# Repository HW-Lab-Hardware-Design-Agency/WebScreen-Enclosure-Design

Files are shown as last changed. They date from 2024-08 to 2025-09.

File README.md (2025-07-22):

   
# WebScreen-Enclosure-Design
## Description

This repository contains design files and technical documentation for the webscreen enclosure. The enclosure has been designed to provide a robust and functional solution, optimizing hardware integration with an improved fastening system using insertion and friction instead of adhesives.



## Main Features

+ Optimized Design: Fastening via insertion and friction for greater stability and easy assembly.

+ Compatibility: Specifically designed for the webscreen with a custom support base.

+ Recommended Materials: `PLA`, `ABS`, depending on mechanical and thermal resistance requirements.

+ Source Files: Models in [Freecad](https://www.freecad.org/) format.

## Project structure
  • `/Documentation` - Contains the technical manual with specifications and assembly guides..

  • `/STL_Files` - contains design files in .STL formats for 3D printing.

  • `/Editable_files_in_Freecad` - contains design files in .FCStd formats for 3D edition in [Freecad](https://www.freecad.org/).

## Assembly Instructions
  • Watch the [assembly instructions video](https://www.youtube.com/watch?v=CHH5L84EN5o&t=1s).

  • You can also find a detailed [guide to fix the webscreen](https://es.ifixit.com/Desmontaje/WebScreen+Teardown/181334).

## 3D Printing Specifications for WebScreen
To ensure optimal quality and functionality, please follow these printing settings:

  • Layer height: 0.2 mm
  
  • Infill density: 20%
  
  • Infill pattern: Gyroid or Grid (for strength and flexibility)
  
  • Wall thickness: 1.2 mm (at least 3 perimeters)
  
  • Top/bottom layers: 4
  
  • Printing material: PLA, PETG, or ABS (PETG recommended for better durability)
  
  • Nozzle diameter: 0.4 mm
  
  • Print speed: 50-60 mm/s
  
  • Supports: Only if necessary (use tree supports for easy removal)
  
  • Bed adhesion: Brim or Raft if necessary (for better grip)
  
  • Cooling fan: 100% (except for the first few layers)
  
  • Temperature Nozzle: 200-220°C (depending on material)
  
  • Temperature Bed: 60°C for PLA, 80°C for PETG, 100°C for ABS

Make sure your print bed is well-leveled, and the first layer adheres properly to avoid warping. If using ABS, print in an enclosed chamber to prevent warping and cracking.
For best results, post-processing such as light sanding or acetone smoothing (for ABS) can be applied.

## License
This project is open source. See the [LICENSE](https://github.com/HW-Lab-Hardware-Design-Agency/WebScreen-Enclosure-Design/blob/main/LICENSE) file for details.

## Contact

For inquiries or contributions, please contact the development team through the repository issues or via email.



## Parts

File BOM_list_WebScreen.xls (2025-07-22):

Pos | Part | Qty
1 | Pcb | 1
2 | Bottom Enclosure | 1
3 | On/Off Button | 1
6 | Mount Adjustment Hook | 2
7 | Pivot support | 1
8 | Screw M3*10 | 2
9 | Screw M1.4*0.3*3mm | 2
12 | Main body Enclosure | 1
13 | Display DO0200FS01 | 1
14 | Top Enclosure | 1
15 | Cap | 1

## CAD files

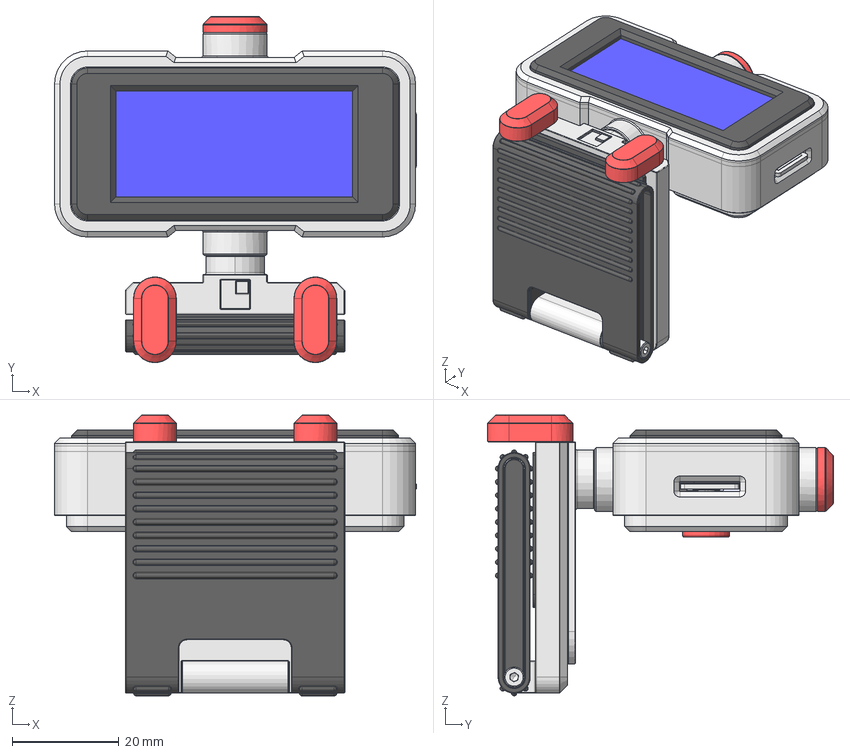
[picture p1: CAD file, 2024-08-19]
Small Version/main_body.FCStd
67.7 x 64.7 x 52.5 mm
SS_Mount Body Upper V1.0
SS_Mount Lower Outer Rubber V1.0
SS_Mount Lower Inner V1.0
socket head cap screw_am_B18.3.1M - 2 x 0.4 x 3 Hex SHCS -- 3NHX003
socket head cap screw_am_B18.3.1M - 2 x 0.4 x 3 Hex SHCS -- 3NHX004
SS_Mount Upper Rubber Protector V1.0
female thread002
SS_Mount Adjustment Hook V1.002
SS_Mount Adjustment Hook V1.003
L_0402_1005Metric
C_0402_1005Metric
r_0402_h040
PRO-OB-440
C_0402_1005Metric002
ASSEMBLY
C_0603_1608Metric
r_0402_h042
C_0603_1608Metric002
L_0402_1005Metric002
C_0402_1005Metric004
LED_0603_1608Metric
BRFL2518T1R5M
BRFL2518T1R5M001
BRFL2518T1R5M002
ASSEMBLY001
ASSEMBLY002
R_0402_1005Metric
r_0402_h044
r_0402_h046
C_0402_1005Metric006
C_0402_1005Metric008
MicroSD_Socket
MicroSD_Socket001
MicroSD_Socket002
MicroSD_Socket003
MicroSD_Socket004
MicroSD_Socket005
MicroSD_Socket006
MicroSD_Socket007
MicroSD_Socket008
MicroSD_Socket009
MicroSD_Socket010
MicroSD_Socket011
MicroSD_Socket012
MicroSD_Socket013
MicroSD_Socket014
MicroSD_Socket015
MicroSD_Socket016
MicroSD_Socket017
MicroSD_Socket018
MicroSD_Socket019
MicroSD_Socket020
MicroSD_Socket021
MicroSD_Socket022
LQM2HPN1R0MJ0L
LQM2HPN1R0MJ0L001
LQM2HPN1R0MJ0L002
Crystal_SMD_3225-4Pin_3.2x2.5mm
ASSEMBLY003
ASSEMBLY004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

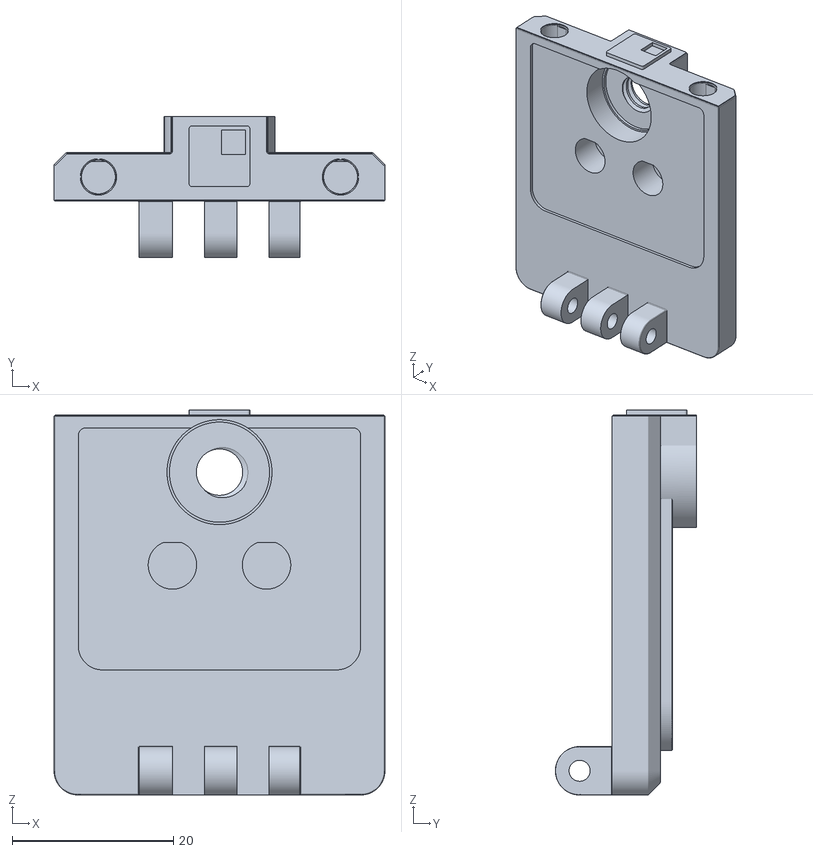
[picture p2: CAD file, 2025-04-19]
STL_Files/Main_body(White).stl
41.0 x 17.5 x 47.7

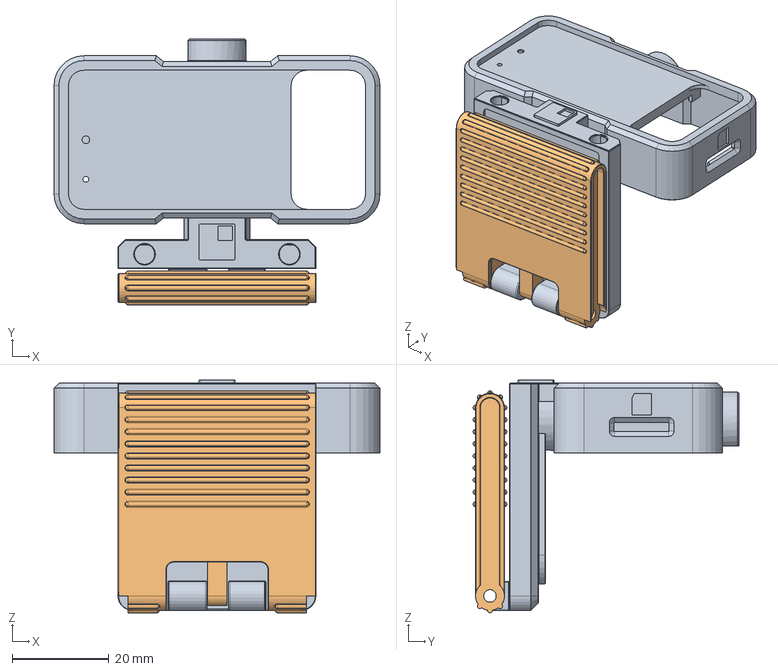
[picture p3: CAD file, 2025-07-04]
Editable_files_in_Freecad/Assembly_v2.FCStd
67.5 x 55.1 x 48.2 mm
Main_body_001
pivot_support_001

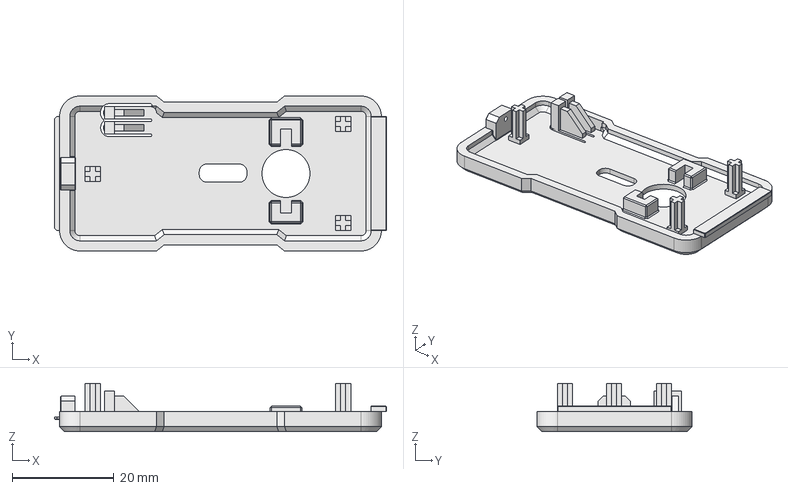
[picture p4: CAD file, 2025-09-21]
Editable_files_in_Freecad/Bottom_Enclosure.FCStd
65.1 x 30.4 x 9.50 mm

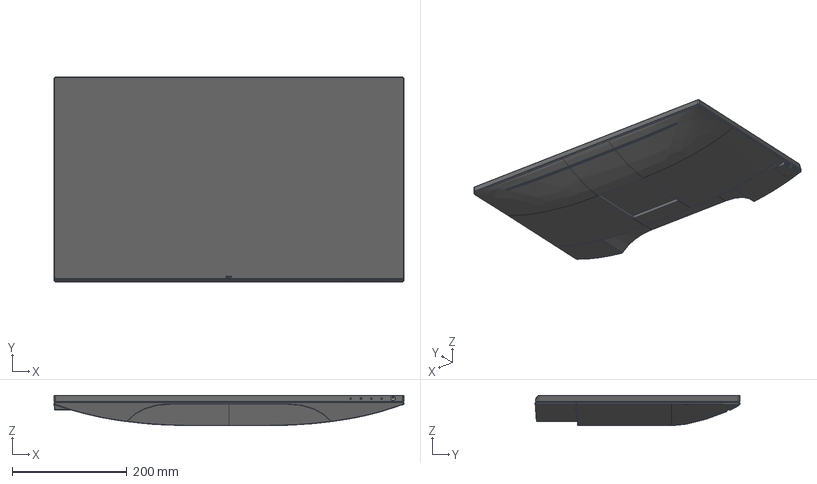
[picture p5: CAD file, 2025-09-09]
Editable_files_in_Freecad/Monitor.FCStd
610.0 x 357.0 x 53.1 mm
Dell 27 monitor
Dell 27 monitor001
Dell 27 monitor002
Dell 27 monitor003
Dell 27 monitor004
Dell 27 monitor005
Dell 27 monitor006
Dell 27 monitor007
Dell 27 monitor008
Dell 27 monitor009
Dell 27 monitor010
Dell 27 monitor011
Dell 27 monitor012
Dell 27 monitor013
Dell 27 monitor014
Dell 27 monitor015
Dell 27 monitor016
Dell 27 monitor017
Dell 27 monitor018
Dell 27 monitor019
Dell 27 monitor020
Dell 27 monitor021
Dell 27 monitor022

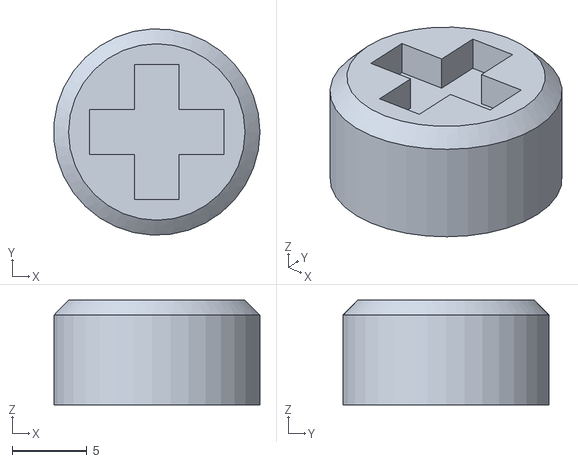
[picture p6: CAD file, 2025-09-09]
STL_Files/Cap(red).stl
13.8 x 13.8 x 7.00

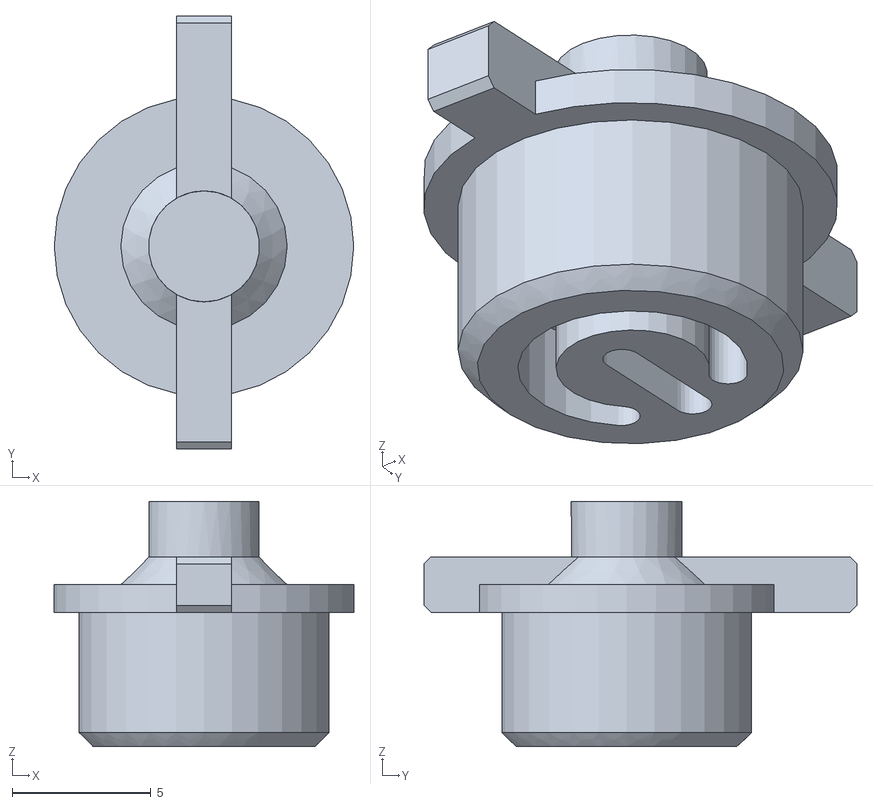
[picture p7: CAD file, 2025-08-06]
STL_Files/Red_buttom(red).stl
10.8 x 15.6 x 8.84

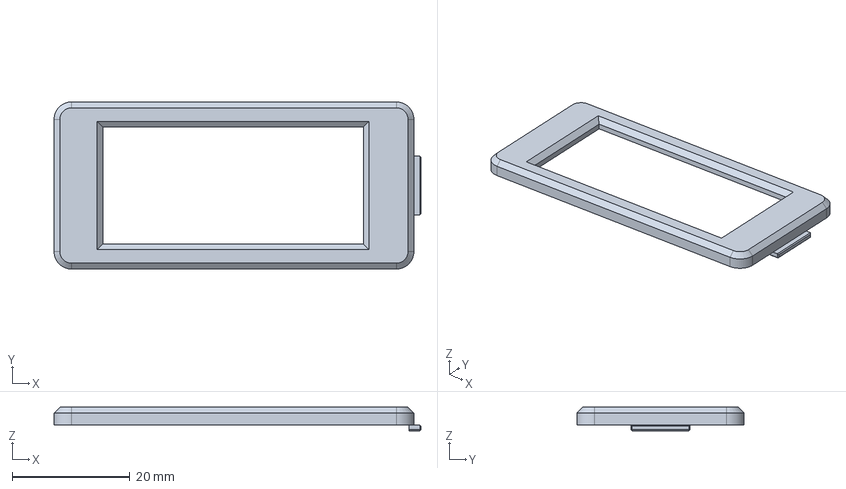
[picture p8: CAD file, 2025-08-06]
Editable_files_in_Freecad/Top_Enclosure.FCStd
62.3 x 28.4 x 4.00 mm

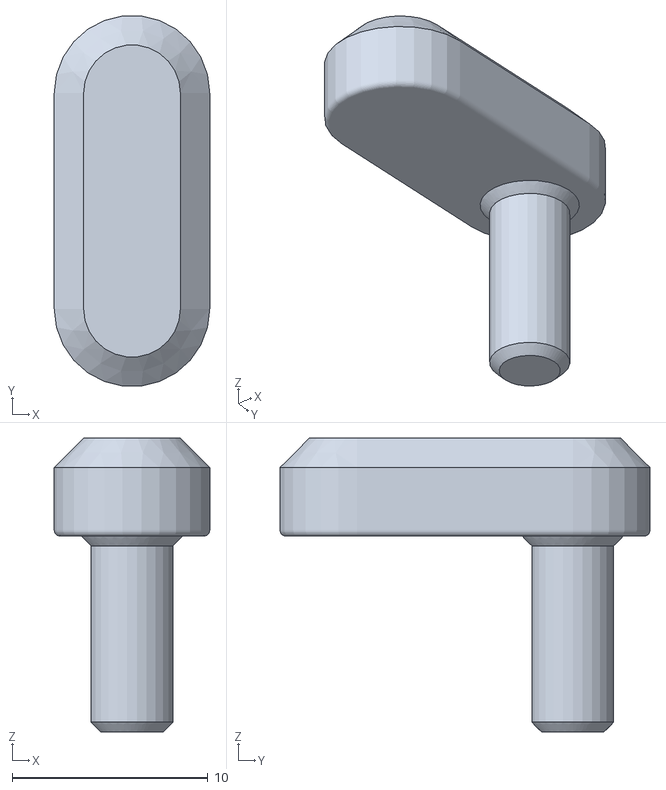
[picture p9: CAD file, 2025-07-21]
STL_Files/Mount_Adjustment_hook(Red).stl
7.94 x 18.9 x 15.0

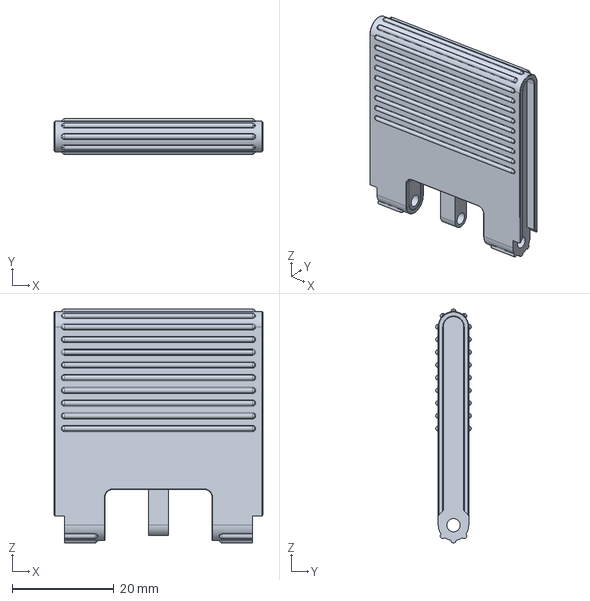
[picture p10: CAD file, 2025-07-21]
Editable_files_in_Freecad/pivot_support.FCStd
41.0 x 7.00 x 46.0 mm

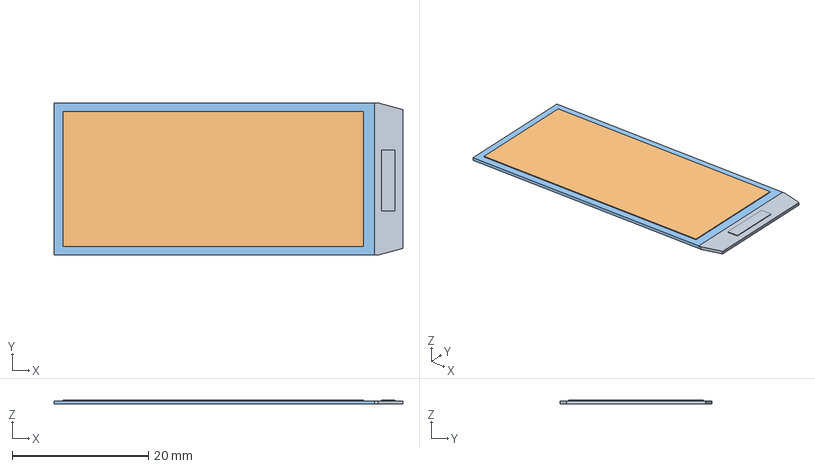
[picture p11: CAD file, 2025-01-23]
Editable_files_in_Freecad/Display_DO0200FS01.FCStd
51.3 x 22.4 x 0.64 mm

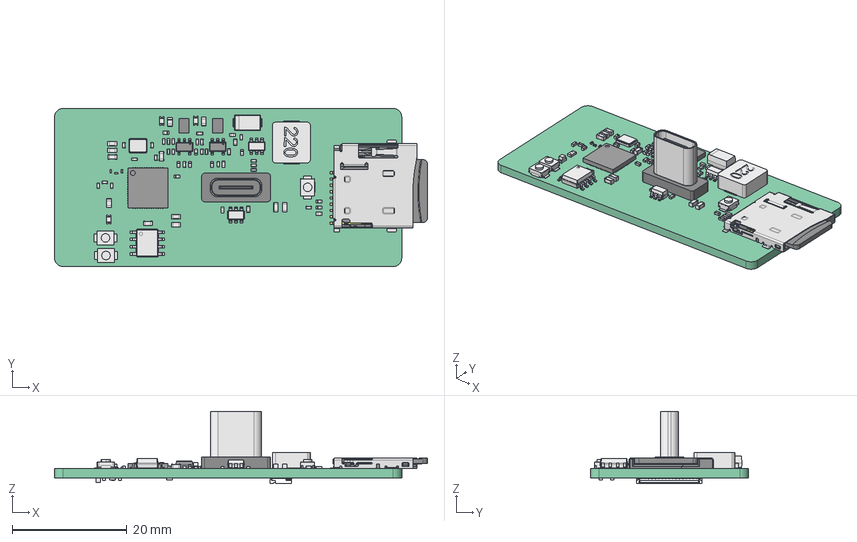
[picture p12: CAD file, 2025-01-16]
Editable_files_in_Freecad/Display_pcb.FCStd
65.1 x 27.6 x 12.6 mm
Pcb_686b
R21_r_0402_h040_d01af9244106 x 20
C17_C_0201_0603Metric_b89ab5aa9964 x 2
C4_C_0402_1005Metric_ad35c1dd326c x 24
B3U_1000P x 3
C15_C_0603_1608Metric_17e78e0e3195 x 7
L2_L_0402_1005Metric_cf0443b79bf7 x 2
DS2_LED_0603_1608Metric_Castellated_210b8ad15fde x 3
BRFL2518T1R5M x 2
BRFL2518T1R5M001 x 2
BRFL2518T1R5M002 x 2
c_0603_h078 x 3
U3_SOT_23_6_41fc66089ef8 x 2
Case^MicroSD_Socket
Insert^MicroSD_Socket
Brace^MicroSD_Socket
Spring^MicroSD_Socket
Lid^MicroSD_Socket
Pin_Middle^MicroSD_Socket
Pin_Middle^MicroSD_Socket001
Pin_Middle^MicroSD_Socket002
Pin_Middle^MicroSD_Socket003
Pin_Middle^MicroSD_Socket004
Pin_Short^MicroSD_Socket
Pin_Long^MicroSD_Socket
Pin_Long^MicroSD_Socket001
MicroSD_Card^MicroSD_Socket
MicroSD_Card^MicroSD_Socket001
MicroSD_Card^MicroSD_Socket002
MicroSD_Card^MicroSD_Socket003
MicroSD_Card^MicroSD_Socket004
MicroSD_Card^MicroSD_Socket005
MicroSD_Card^MicroSD_Socket006
MicroSD_Card^MicroSD_Socket007
MicroSD_Card^MicroSD_Socket008
Pin_CardIn^MicroSD_Socket
Y1_Crystal_SMD_3225-4Pin_3.2x2.5mm_d5f2c4821880
PinsArrayL x 2
PinsArrayL001 x 2
PinsArrayL002 x 2
PinsArrayR x 2
PinsArrayR001 x 2
D1_D_SMA_0f2286977986
Cuerpo
L3_L_0201_0603Metric_520d9d73161f
soic_8_39x49_p127
ThermalPin
PinsArrayLR
PinsArrayLR001
PinsArrayLR002
PinsArrayLR003
PinsArrayLR004
PinsArrayLR005
PinsArrayLR006
PinsArrayLR007
PinsArrayLR008
PinsArrayLR009
PinsArrayLR010
PinsArrayLR011
PinsArrayLR012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

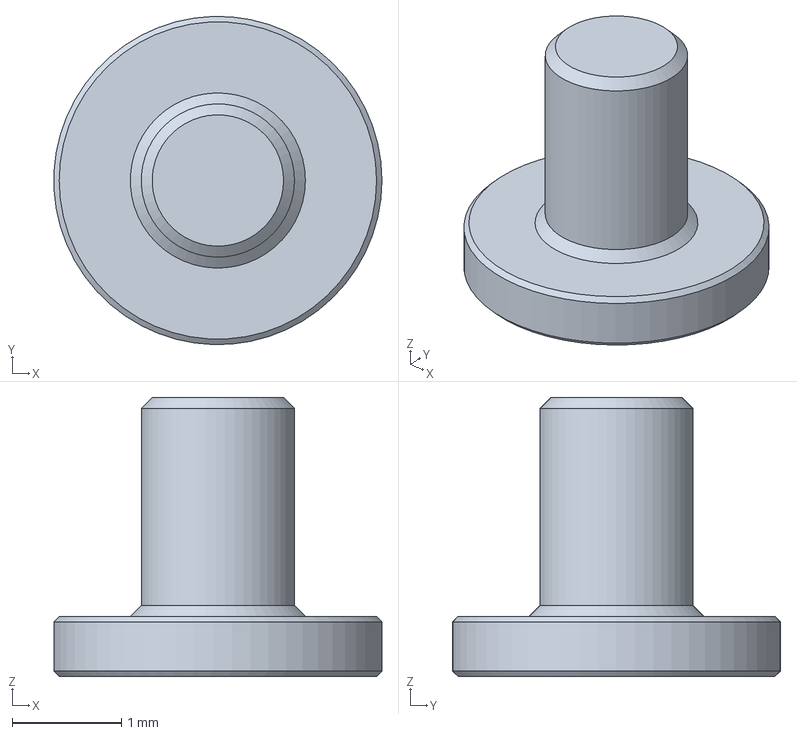
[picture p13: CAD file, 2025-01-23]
Editable_files_in_Freecad/M1.4_0.3_3mm_Screw.FCStd
3.00 x 3.00 x 2.55 mm

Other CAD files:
STL_Files/Bottom_enclosure(white).stl
Editable_files_in_Freecad/Cap.FCStd
STL_Files/Top_Enclosure(Black).stl
Editable_files_in_Freecad/Red_Buttom.FCStd
Editable_files_in_Freecad/Mount_adjustment_hook.FCStd
Editable_files_in_Freecad/M3x10 Philips Screw.FCStd

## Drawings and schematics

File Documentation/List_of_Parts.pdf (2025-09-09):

## List of P arts

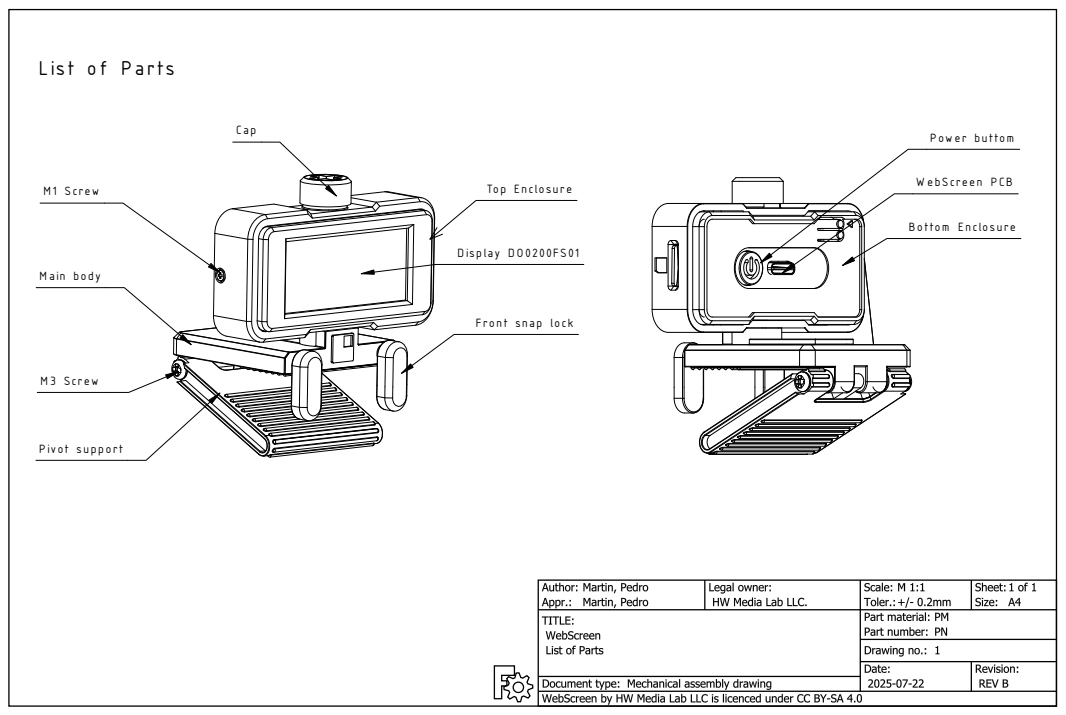
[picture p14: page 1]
Cap; Top Enclosure; M ain body; P ivot support; M 3 S cre w; M 1 S cre w; D isplay D O 0200F S 01; P o w er buttom; B ottom Enclosure; W eb S creen P C B

Front snap lock

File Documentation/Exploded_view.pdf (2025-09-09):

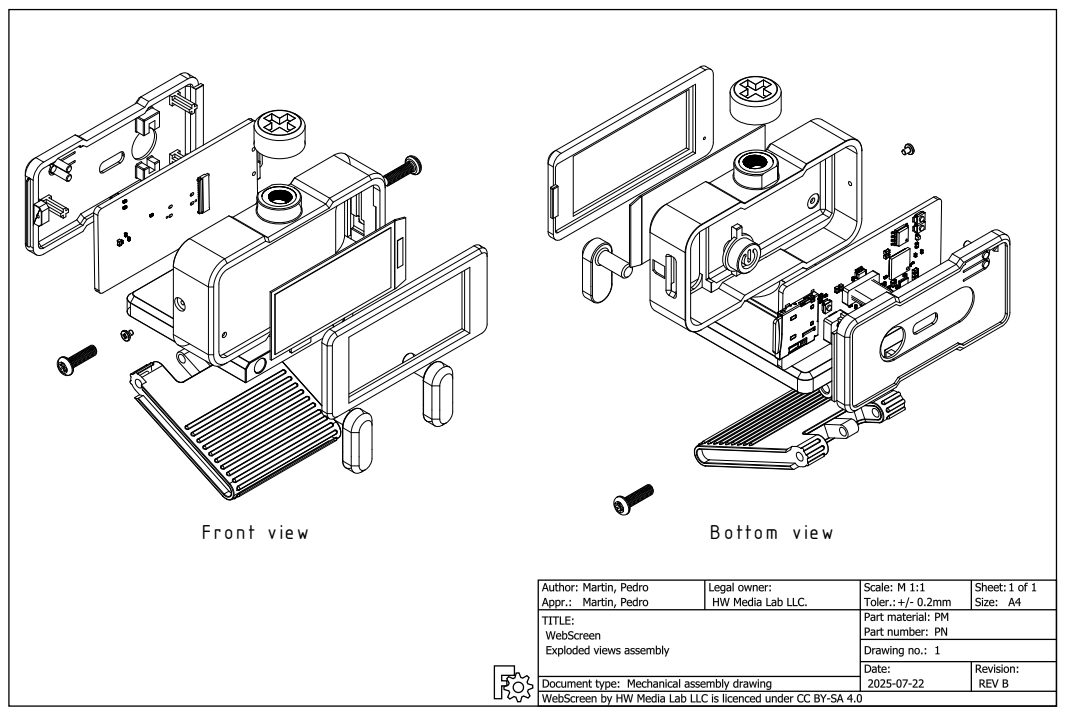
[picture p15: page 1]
Front vie w; B ottom vie w

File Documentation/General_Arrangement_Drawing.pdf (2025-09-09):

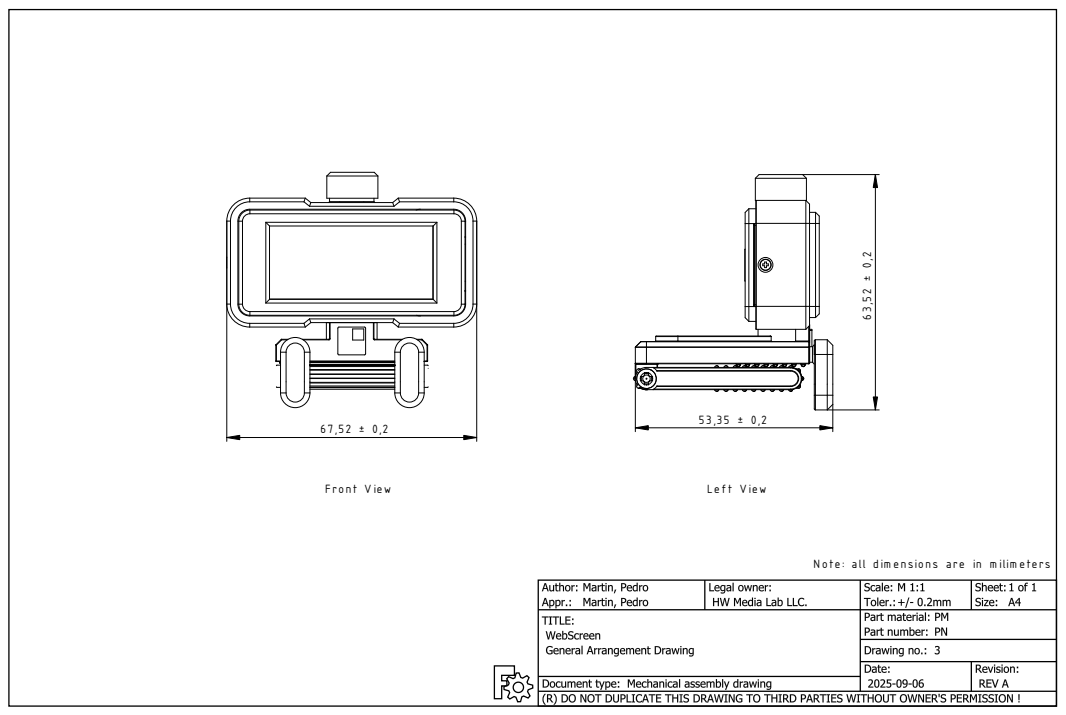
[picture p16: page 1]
Front V ie w; Left V ie w

N ote: all dim ensions are in m ilim eters

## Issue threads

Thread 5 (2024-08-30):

Multiple issues: Top cap, screw sizes, bottom clamps, etc

eleonel, 2024-08-30:
- Top cap: Increase height a tiny bit (what do you think?)
- Small gap: I’m afraid of this gap, maybe it is because of my printer but we should check we have no visible gaps.
- Bottom screw: It doesn’t adjust very well, compared with the top one. The top one adjusts quite tight.
- Clamps: For some reason the left clamp is not as tight as the right one, maybe it is my printer? I printed the files from the folder, so maybe one of them is smaller in diameter than the other?

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

**Printing settings (Bambu Lab P1P)**

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

eleonel, 2025-04-14:
All issues are resolved now with the latest commit.

Closed 2025-04-14.

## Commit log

2024-07-08 Create Bottom Enclosure
    [Bottom_Enclosure.FCStd]
2024-07-11 First iteration of the large version
    [Assembly.FCStd, Bottom_Enclosure.FCStd, Bottom_Enclosure.stl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]
2024-07-15 Add small version enclosure
    [Top_Enclosure.FCStd, Top_Enclosure.stl, Top_Enclosure_Black.FCStd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]
2024-07-18 Width of 2mm for front enclosure (Small Version)
    [Top_Enclosure.FCStd, Top_Enclosure.stl]
2024-07-19 Add support for enclosure and support for videocam
    [Top_Enclosure.FCStd, Top_Enclosure.stl]
2024-07-24 Small version Enclosure. Design with one screw. First functional iteration
    [Bottom_Enclosure.stl, Top_Enclosure.FCStd, Top_Enclosure.step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]
2024-07-29 Exploded view Diagram
    [Bottom_Enclosure.stl, Top_Enclosure.FCStd, Top_Enclosure.step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]
2024-08-05 Add 3d model of PCB v2
    [main_body.FCStd]
2024-08-07 Add slot for TF card memory
    [main_body.FCStd]
2024-08-12 New screw for bottom enclosure (Use M1 screws)
    [Bottom_Enclosure.stl, Top_Enclosure.stl, Top_Enclosure_Black.stl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]
2024-08-17 Add SS_Mount_Adjustment_Hook large version
    [Mount_Lower_Rubber_Inner.stl, Mount_Upper_Rubber_Protector.stl, SS_Mount_Adjustment_Hook_large_version.FCStd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]
2024-08-17 Add STL File SS_Mount_Adjustment_Hook_large_version
    [SS_Mount Adjustment Hook V1.0.stl]
2024-08-19 Fix Mount Adjustment Hook large version
    [SS_Mount_Adjustment_Hook_large_version.FCStd, SS_Mount_Adjustment_Hook_large_version.stl, Thread_Cap.stl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]
2024-08-29 Version with nut and screw incorporated in the top enclosure part
    [Bottom_Enclosure.stl, Display_pcb.stl, Thread_Cap_v2.stl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]
2024-12-09 Init enclosure production 3d printing
    [Bottom_Enclosure.stl, Display_pcb.stl, Locking_hinge_part1(black).stl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]
2024-12-09 Init files for production 3d printing
2024-12-11 Add STEP Files
    [Bottom_enclosure(white).step, Enclosure_display(black).step, Mount_adjustment_hook_1(red).step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]
2024-12-17 Add reset and boot buttons to WebScreen enclosure
    [Bottom_Enclosure.FCStd, Bottom_enclosure(white).step, Bottom_enclosure(white).stl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]
2024-12-17 Fix STL File Bottom Enclosure
    [Bottom_enclosure(white).stl]
2024-12-20 Marked reset button for identification
    [Bottom_Enclosure.FCStd, Bottom_enclosure(white).step, Bottom_enclosure(white).stl]
2025-01-07 Add memory card symbol to top enclosure
    [Top_enclosure(white).stl]
2025-01-16 Updated enclosure bottom with unique guide for on/off button positioning; modified on/off button design
    [Bottom_Enclosure.FCStd, Bottom_enclosure(white).step, Bottom_enclosure(white).stl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]
2025-01-23 Red Cap Change, Exploded Assembly Drawing for documentation, and .glb File Generation for Web Viewer
    [14_12_Round_head_screw.FCStd, BOM_list_WebScreen.xlsx, Bottom_Enclosure.FCStd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]
2025-02-10 DREIS Front Customization Base and Insertion-Based Pad Mounting
    [Main_body(White).stl, Mounting_pad(black).stl, Pad.FCStd]
2025-02-14 Enclosure polished design
    [Bottom_enclosure(white).step, Bottom_enclosure(white).stl, Cap(red).step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]
2025-03-09 Fix errors in .STL Files
    [RedButtom(red).stl, Top_enclosure(black).stl]
2025-04-13 Update FreeCAD source files and exported STL models
    [Cap(red).stl, Cap.FCStd, Enclosure_display(black).stl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]
2025-04-15 Fix corrupted File Enclosure display´
    [Enclosure_display(black).stl, Top_Enclosure.FCStd]
2025-04-19 Added wall thickness for proper 45 degrees printing
2025-04-19 Added stl File Main body
    [Main_body(White).stl]
2025-04-19 Init commit base integration
    [Main_body(White).stl, Main_enclosure(white).stl, Red_Buttom.FCStd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]
2025-04-19 Change on red_buttom stl file
    [Red_Buttom.FCStd, Red_buttom(red).stl]
2025-04-22 Change pivot support to production
    [Locking_hinge_part1(black).stl, pivot_support.FCStd, pivot_support_1.FCStd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]
2025-05-30 Change in mechanical fastening: Snap fit in Top Enclosure
    [Bottom_enclosure(white).stl, Enclosure_display(black).stl, Main_body(White).stl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]
2025-05-30 Fix .STL File Top Enclosure
    [Top_Enclosure(Black).stl]
2025-06-03 Reverted snap-fit, returned to mechanical fastening on Top Enclosure
    [14_12_Round_head_screw.FCStd, Top_Enclosure(Black).stl, Top_Enclosure.FCStd]
2025-06-28 changed pivot support base
    [Assembly_v2.FCStd, pivot_support.FCStd]
2025-07-04 New pivot support with 3 mm diameter
2025-07-09 Refined M3 mounting - Hole resize & Pad removal
    [Pad.FCStd, pivot_support.FCStd]
2025-07-12 Refined M3 head recess on pivot support + resized front hook diameter for interference fit (to be validated)
    [Mount_Adjustment_hook(Red).stl, Mount_adjustment_hook.FCStd, pivot_support.FCStd]
2025-07-14 Add mounting hole in top enclosure & refine hook diameter support
    [Mount_Adjustment_hook(Red).stl, Mount_adjustment_hook.FCStd, Top_Enclosure(Black).stl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]
2025-07-21 Multiple improvements around mounting, pad and hooks.
    * New pivot support with 3 mm diameter
    * Refined M3 mounting - Hole resize & Pad removal
    * Refined M3 head recess on pivot support + resized front hook diameter for interference fit (to be validated)
    * Add mounting hole in top enclosure & refine hook diameter support
    ---------
    [Mount_Adjustment_hook(Red).stl, Mount_adjustment_hook.FCStd, Pad.FCStd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]
2025-07-22 Enlarged hole in the main body to improve screwing of the top enclosure
    [BOM_list_WebScreen.xls, BOM_list_WebScreen.xlsx, Bottom_Enclosure.FCStd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]
2025-07-22 Change Main Body .STL File
2025-08-04 Change the hole to an M1 threaded hole
    [Top_Enclosure(Black).stl, Top_Enclosure.FCStd]
2025-08-06 Adjust screw hole diameter in top enclosure and add 1mm to bottom on-off
    [Red_Buttom.FCStd, Red_buttom(red).stl]
2025-09-09 Reinforced standoffs in bottom enclosure for RESET/BOOT switch support
    [Bottom_Enclosure.FCStd, Bottom_enclosure(white).stl, Cap(red).stl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]
2025-09-21 Increase bottom enclosure wall thickness from 0.75mm to 1mm for printability
    [Bottom_Enclosure.FCStd, Bottom_enclosure(white).stl]

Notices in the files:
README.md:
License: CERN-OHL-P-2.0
